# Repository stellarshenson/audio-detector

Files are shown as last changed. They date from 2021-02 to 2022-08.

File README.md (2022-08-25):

# Audio Trigger / Detector
This device listens for an audio signal at the RCA input and in response turns the audio equipment on using IR remote code or a relay. It als turns the audio equipment off when there was no audio signal detected for longer than 10min

## Initial Setup ##

### Installation ###
* Connect the RCA splitter to the RCA socket of the device. 
* Connect one end of the 3.5mm jack cable to the device and the other one to the audio amplifier IR input.
* Connect mini-usb power cable 

### Use ###
When powered, system indicates if any pre-recorded IR codes were found by blinking slowly every 2 seconds. 
If not, the fast blinkng indicates that you need to set-up the device. You need to press and hold the button. 

It will initiate 2-stage recording, first AUDIO START code and AUDIO STOP code. 
System indicates the recording status with a LED: slow blinking for the 1-st stage and fast blinking for the 2-nd. 

Setting up device sensitivity is simple - done by pressing the device button once while playing audio.
The device will listen to the audio signal for a short while and set the sensitivity to the given audio volume.

### Status Leds ###
* **fast blinking after startup** - device was not configured yet, hold button to record IR codes and press button once to record trigger audio volume
* **slow blinking after startup** - everything is ok, device waits for the audio signal
* **led stays on** - audio detected

* **fast blinking after button hold** - device waits for your first infrared remote signal
* **slower blinking after button hold** - device waits for your second infrared remote signal
* **fast blinking after button press** - device learns the volume level for which it should trigger

## Arduino ##
The board used is the Arduino Nano and the libraries:
* **arduino-fsm stellarshenson fork** - State Machine was implemented with arduino_fsm state machine library https://github.com/jonblack/arduino-fsm. This project however uses my fork of the library to allow timed transitions reset: https://github.com/stellarshenson/arduino-fsm. Pull was already requested from the *arduino-fsm* owner, hopefully my fork will be merged soon
* **IRRemote v2.6.1** - IR code recording and sending was implemented with library https://github.com/z3t0/Arduino-IRremote
* **JLed v4.11** - non-blocking led library used for various blinking patterns
* **EnableInterrupt v1.1.0** - simple interrupt driver
* **Smoothed 1.2.0** - moving average for signal detection (detecting averaged value)

## State Machine ##
Diagram was generated by http://asciiflow.com/. System defines 4 states:
* state_audio_sense - the default state, device listens for an audio signal
* state_ircode_record - active after holding the button, records remote control codes
* state_audio_start - active when audio was detected, starts the audio system and moves to state_audio_enabled
* state_audio_enabled - active when audio is enabled

					+---------------------+
					| state_ircode_record |
					+---------+--------+--+
							  ^        |
		TRIGGER_IRCODE_RECORD |        | TRIGGER_IRCODE_RECORDED
							  |        v
					+---------+--------+--+
					| state_audio_sense   +----------------------+
					+-------------+-------+                      |
								  ^                              |
		   TRIGGER_AUDIO_DISABLED |         TRIGGER_AUDIO_SENSED |
								  |                              v
					+-------------+-------+             +--------+-----------+
					| state_audio_enabled +<-----+------+ state_audio_start  |
					+---------------------+      |      +--------------------+
												 +
											TRIGGER_AUDIO_ENABLED

## Circuit and PCB ##
Below are the electronics circuit diagram and the board files (600dpi PNG images) for the PCB fabrication

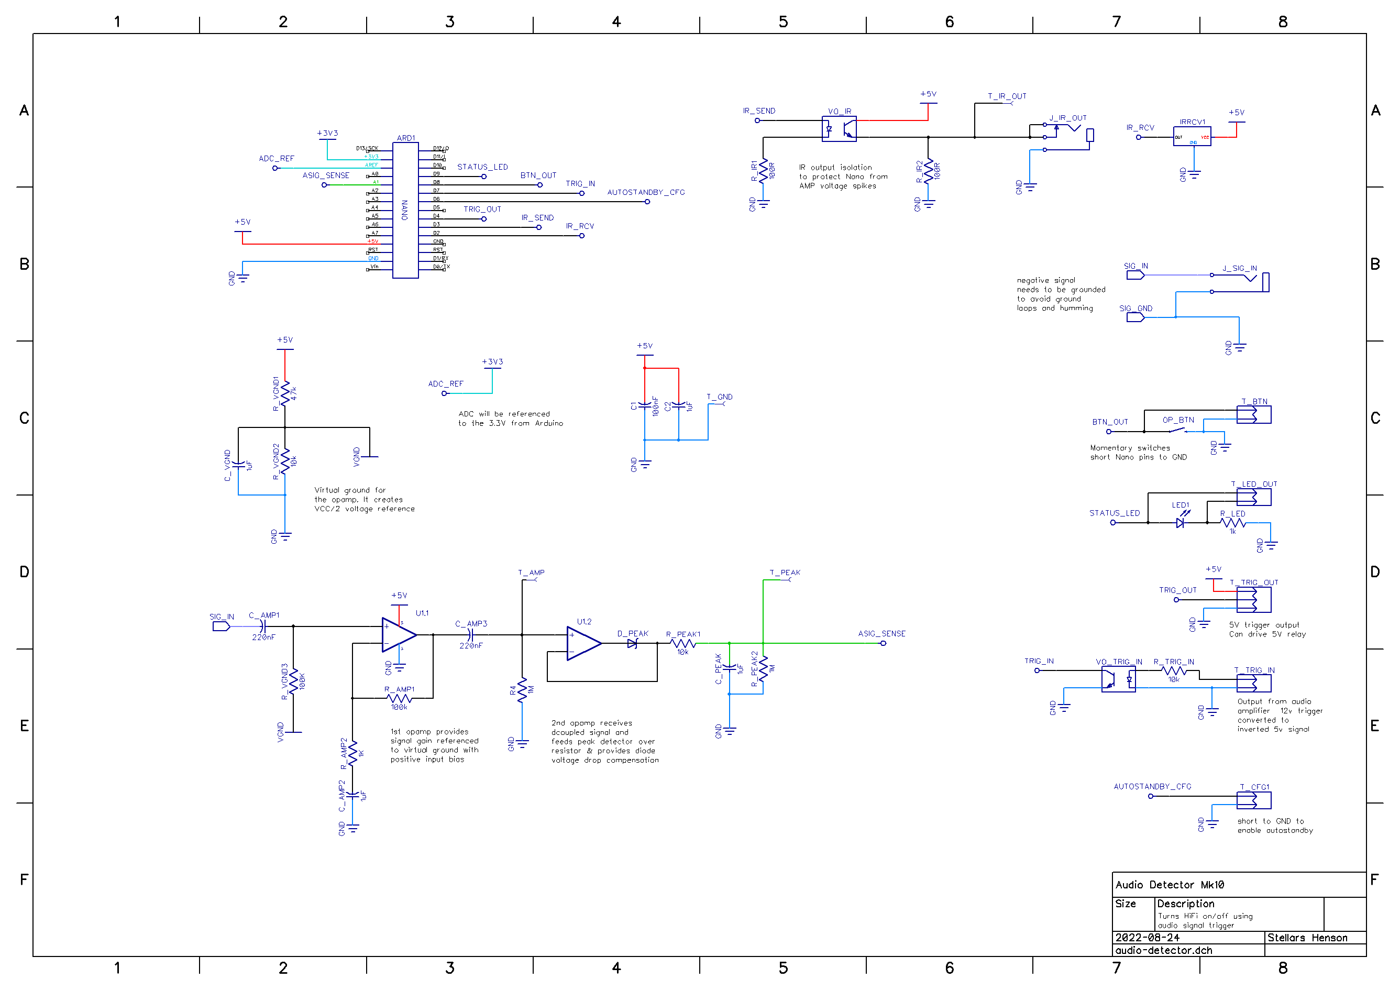
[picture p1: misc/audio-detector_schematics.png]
schematics

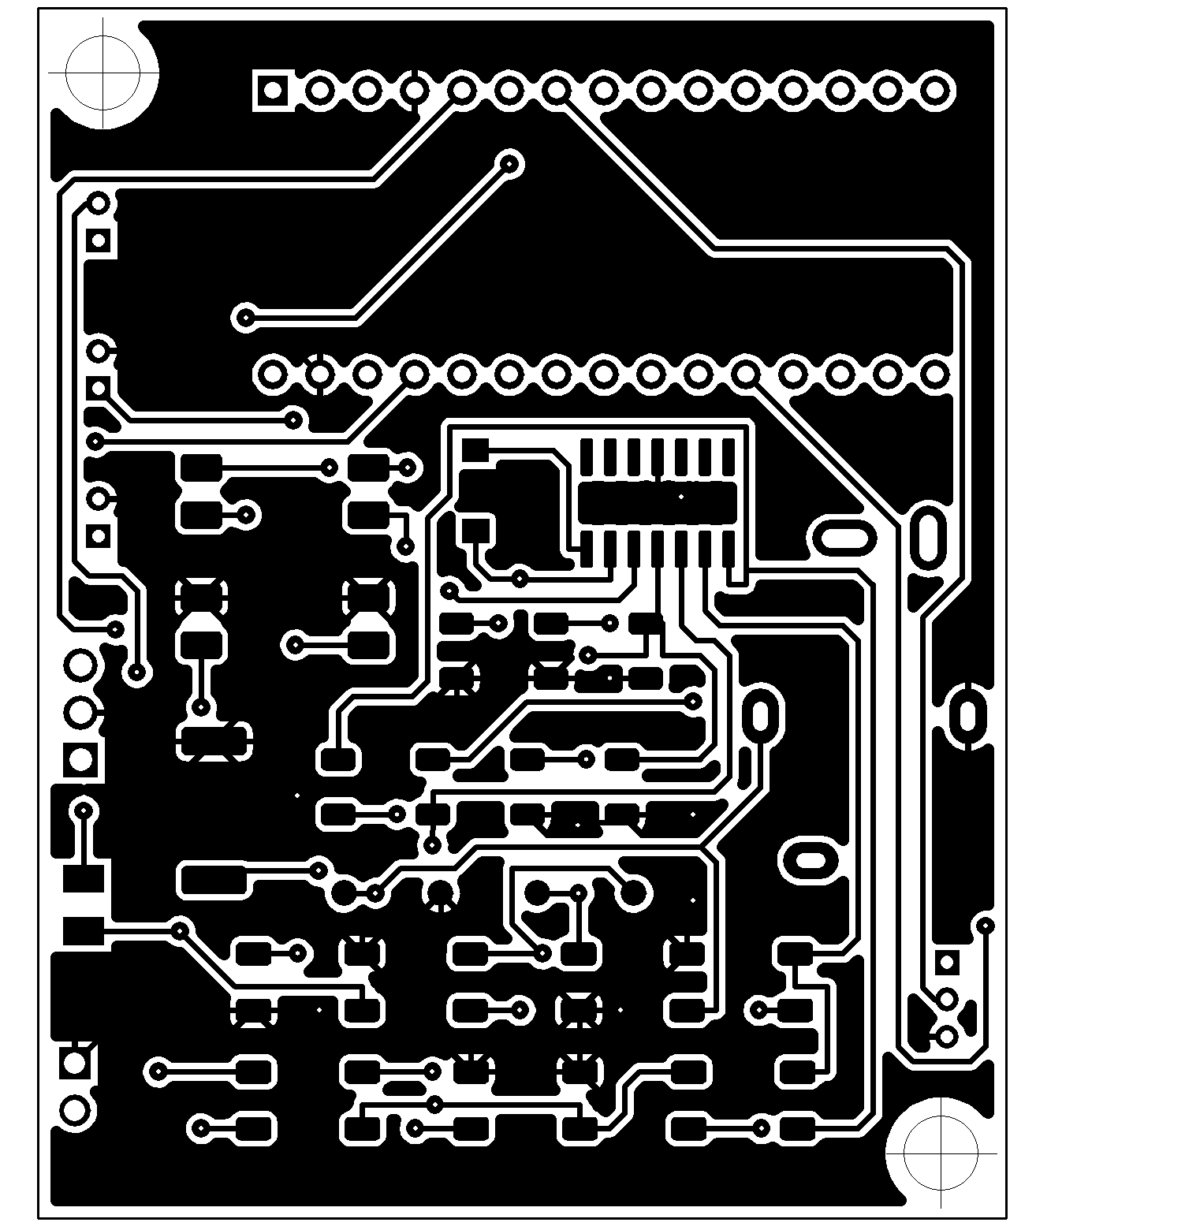
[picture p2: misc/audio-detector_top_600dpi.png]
top

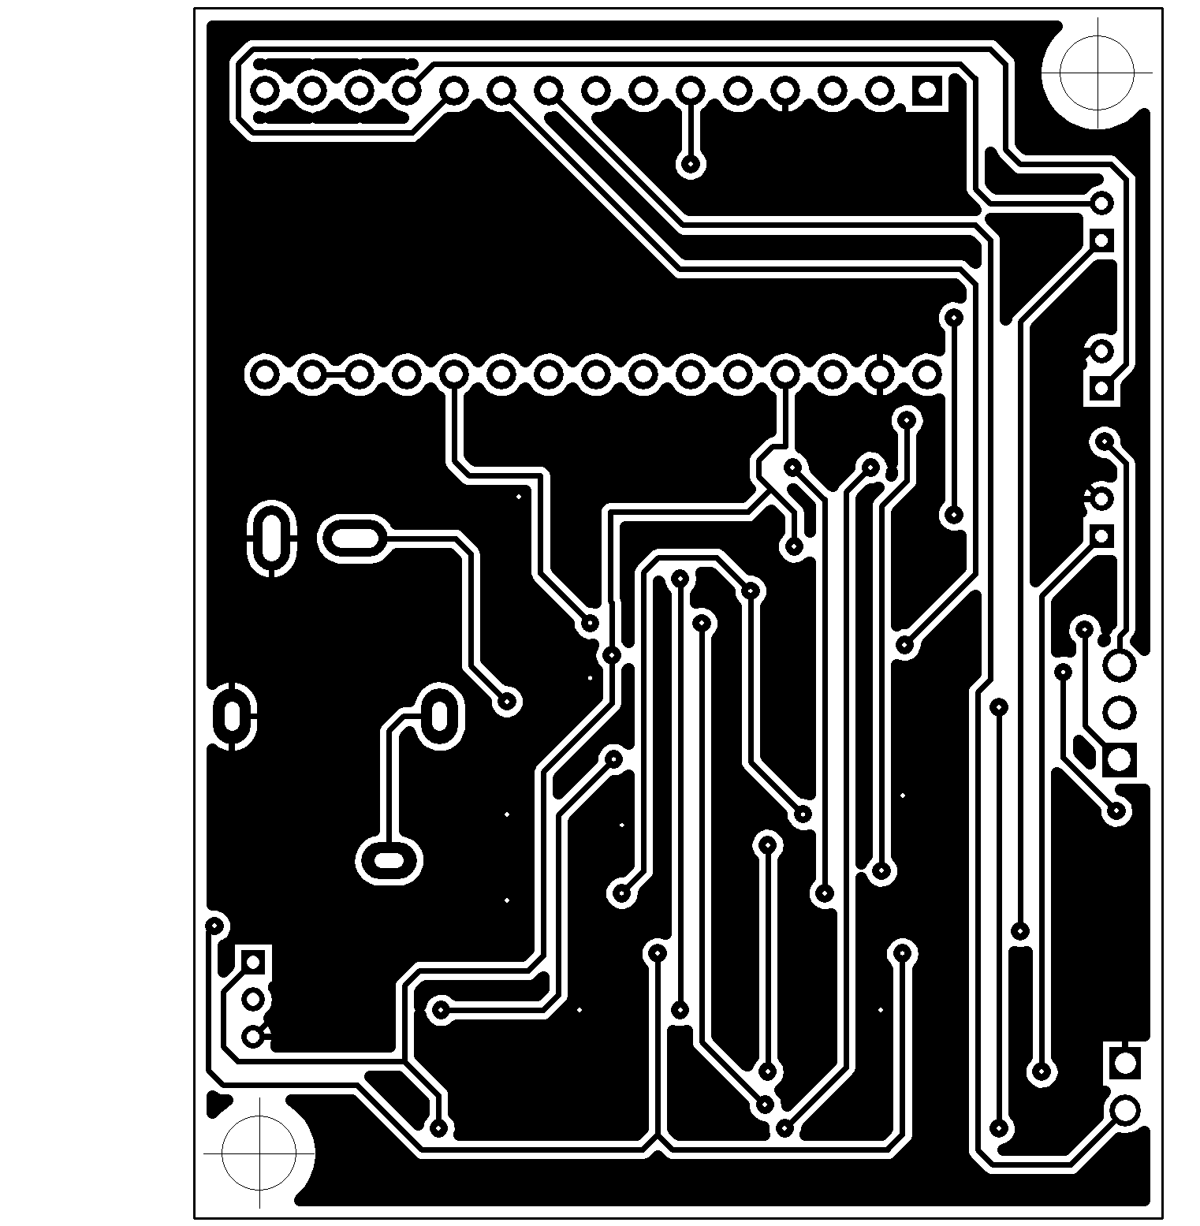
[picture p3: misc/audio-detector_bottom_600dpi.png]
bottom

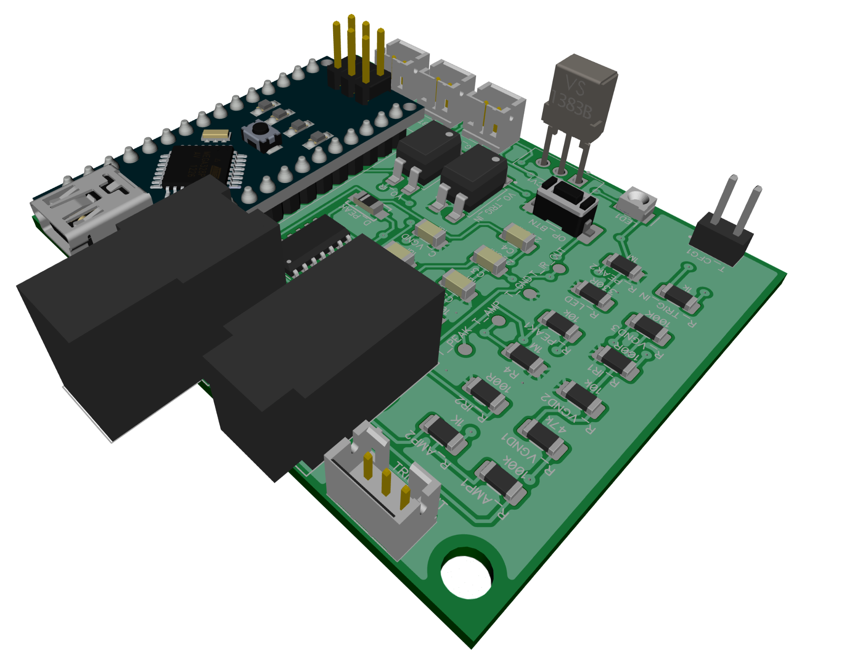
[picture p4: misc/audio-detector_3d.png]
3d

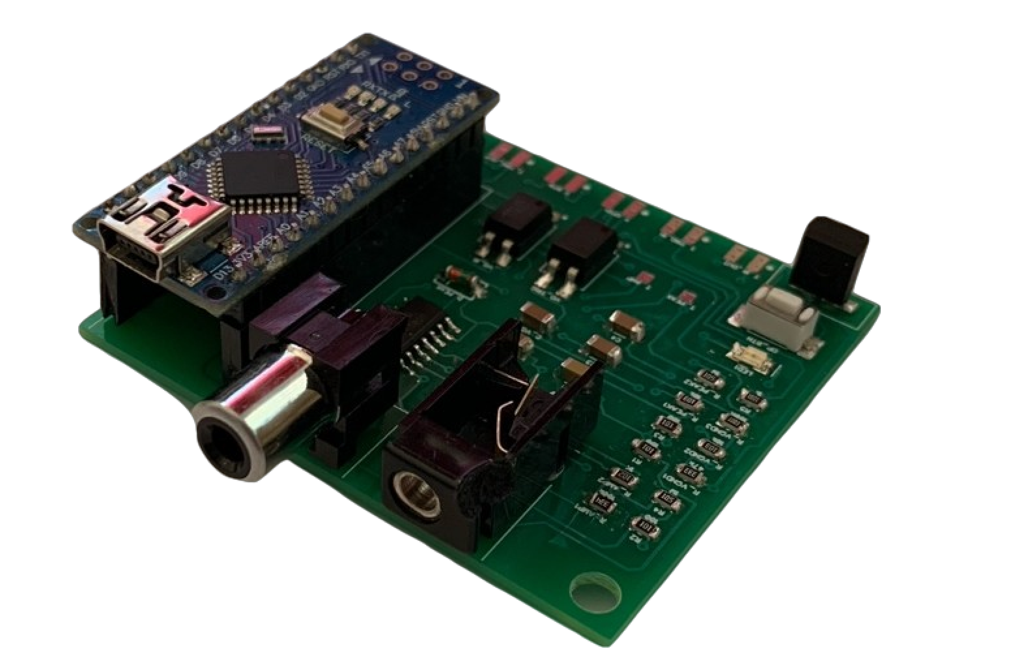
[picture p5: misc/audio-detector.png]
assembled


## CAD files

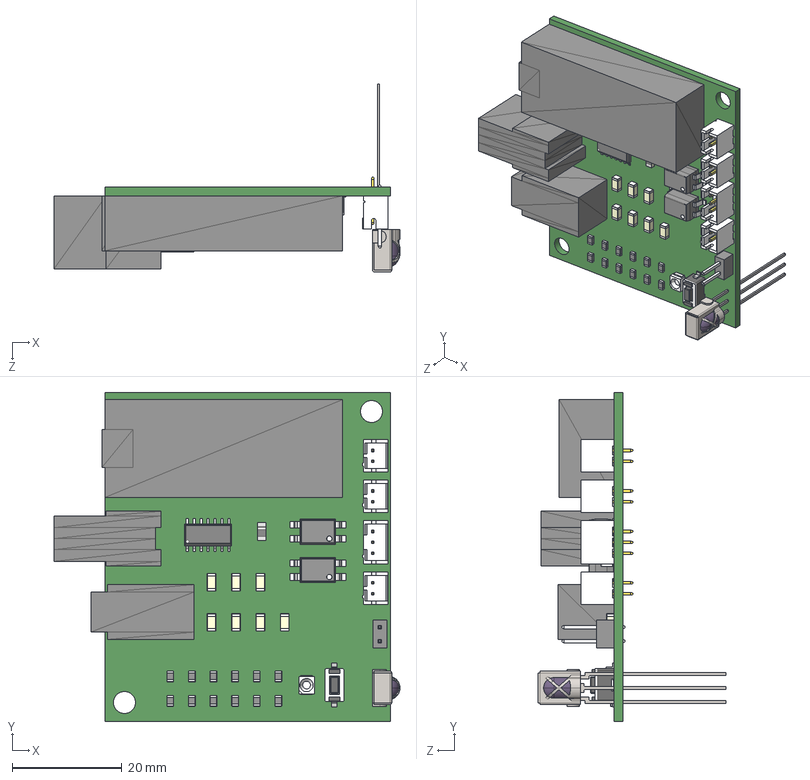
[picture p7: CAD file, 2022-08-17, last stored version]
misc/audio_detector_mk9.step
63.0 x 60.0 x 34.2 mm
Board_audio_detector_mk9
CAP_1206_N x 7
dio_1206
VS1383B
aa3528
Tactile_Switch_SMD
RES_0805_N x 12
B2B-PH-K-S x 3
B3B-PH-K-S
soic-14_150mil
TV-817S-A x 2
ARDUINO_NANO
Unitra_3.5mm_Audio_Jack
RCJ-041

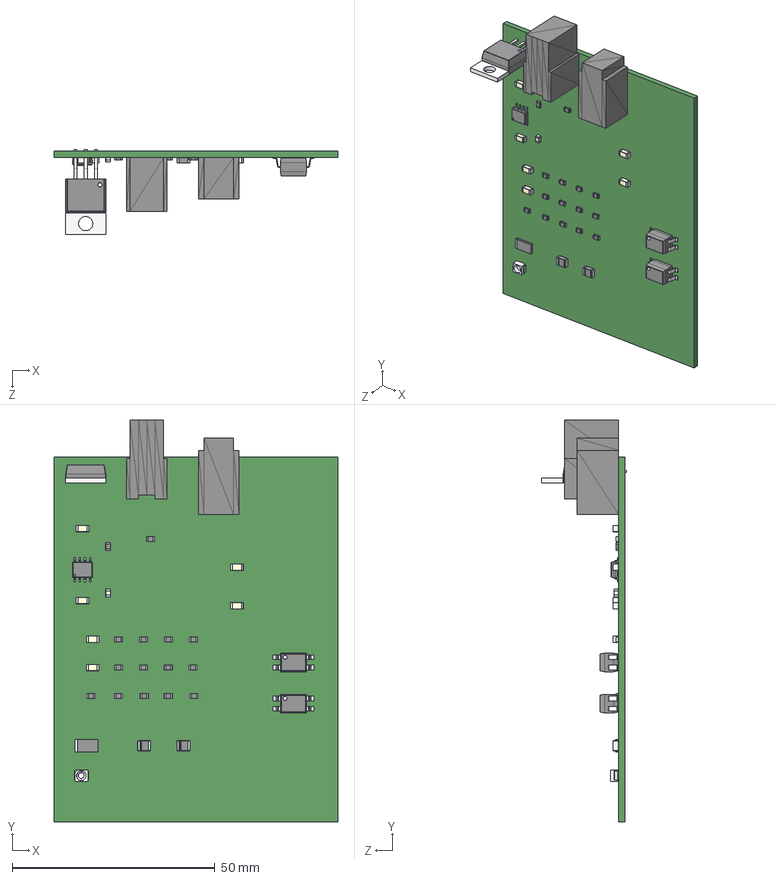
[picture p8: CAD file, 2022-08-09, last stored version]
misc/audio-detector.step
70.0 x 99.2 x 20.9 mm
Board_audio-detector
CAP_1206_N x 6
CAP_0805_N
DIO_1210_N x 2
ICL7660CSA
TSOP2236
aa3528
SWITCH_SMD_3x6mm
RES_0805_N x 15
TV-817S-A x 2
Unitra_3.5mm_Audio_Jack
RCJ-041

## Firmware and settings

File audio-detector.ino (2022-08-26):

/*
  Audio detector that triggers on the audio signal at the RCA socket and turns on (and off)
  your audio system using Infrared Remote signal and/or a Relay

                     +-----+
        +------------| USB |------------+
        |            +-----+            |
   B5   | [ ]D13/SCK        MISO/D12[ ] |   B4
        | [ ]3.3V           MOSI/D11[ ]~|   B3
        | [ ]V.ref     ___    SS/D10[ ]~|   B2
   C0   | [ ]A0       / N \       D9[ ]~|   B1
   C1   | [ ]A1      /  A  \      D8[ ] |   B0
   C2   | [ ]A2      \  N  /      D7[ ] |   D7
   C3   | [ ]A3       \_0_/       D6[ ]~|   D6
   C4   | [ ]A4/SDA               D5[ ]~|   D5
   C5   | [ ]A5/SCL               D4[ ] |   D4
        | [ ]A6              INT1/D3[ ]~|   D3
        | [ ]A7              INT0/D2[ ] |   D2
        | [ ]5V                  GND[ ] |
   C6   | [ ]RST                 RST[ ] |   C6
        | [ ]GND   5V MOSI GND   TX1[ ] |   D0
        | [ ]Vin   [ ] [ ] [ ]   RX1[ ] |   D1
        |          [ ] [ ] [ ]          |
        |          MISO SCK RST         |
        | NANO-V3                       |
        +-------------------------------+

  26 Mar 2020: code has been tested and all works with NAD326bee amplifier and Yamaha WXAD-10 streamer
  20 Aug 2022: updated the code with the moving average to elliminate voltage spikes

  Copyright by Stellars Henson 2020-2022
*/

#include <EEPROM.h>
#include <IRremote.h>         //version 2.6.1
#include <Fsm.h>              //arduino-fsm fork by Stellars Henson https://github.com/stellarshenson/arduino-fsm
#include <EnableInterrupt.h>  //version 1.1.0
#include <jled.h>             //version 4.11
#include <Smoothed.h>         //version 1.2.0

#define OUTPUT_IRCODE_SEND_PIN 3 //pin to send the IR code with via optocoupler
#define INPUT_IRCODE_RECV_PIN 2 //pin connected to IR phototransistor
#define INPUT_BUTTON_PIN 8 //learn signal level with single press, learn IR codes on holdpress
#define OUTPUT_STATUS_LED_PIN 9 //single LED
#define OUTPUT_AUDIO_ENABLED_PIN 4 //set to high when audio is enabled
#define INPUT_AUDIOTRIGGER_PIN 7 //connected to the optocoupler that detects the 12V trigger from the amp
#define INPUT_AUDIOSENSE_ADC_PIN A1  //sense audio with ADC. Vref should be 3v3
#define INPUT_CONFIG_AUTOSTANDBY_PIN 6 //configuration pin pullup. If GND than autostandby will be used. 

#define DEBUG_LEVEL 2 //0 - debug off, 1 - essential messages, 2 - full diagnostics
#define AUDIO_START_TIMEOUT 3000 //timeout for the audio start detection
#define AUDIO_STANDBY_TIMEOUT 10* 60000 //timeout for the audio shutdown if no signal (10min)
#define AUDIO_ENABLED_SENSE_INTERVAL 1* 60000 //timeout for checking audio signal in AUDIO_ENABLED (1min)
#define AUDIOSENSE_INIT_THRESHOLD 300 //initial threshold if no config available
#define AUDIOSENSE_AVG_SAMPLES 50 //number of samples for averaging
#define AUDIOSENSE_ADC_INTERVAL 50 //time between samples
#define STARTUP_STABILISE_DURATION 3000 //let the system tabilise for a while (3s)

//triggers for the FSM
#define TRIGGER_IRCODE_RECORD 1
#define TRIGGER_IRCODE_RECORDED 2
#define TRIGGER_AUDIO_DETECTED 3
#define TRIGGER_AUDIO_ENABLED 4
#define TRIGGER_AUDIO_DISABLED 5
#define TRIGGER_AUDIO_LEARN 6
#define TRIGGER_AUDIO_LEARNED 7

//IR receiver setup
#define EXCLUDE_EXOTIC_PROTOCOLS // saves around 900 bytes program space with IRRemote v3.2+
IRrecv irrecv(INPUT_IRCODE_RECV_PIN);
IRsend irsend;
decode_results results;

//nonblocking LED setup
auto led_sense_noconfig = JLed(OUTPUT_STATUS_LED_PIN).Blink(250, 1000).Forever(); //quick blinking if no config
auto led_sense_configok = JLed(OUTPUT_STATUS_LED_PIN).Blink(1000, 2000).Forever(); //long blinking if everything is ok
auto led_audio_enabled =  JLed(OUTPUT_STATUS_LED_PIN).On();
auto led_audio_disabled = JLed(OUTPUT_STATUS_LED_PIN).Off();
auto led_audio_learning = JLed(OUTPUT_STATUS_LED_PIN).Blink(750, 250).Forever();
auto led_ir_recording_1 = JLed(OUTPUT_STATUS_LED_PIN).Blink(100, 100).Forever();
auto led_ir_recording_2 = JLed(OUTPUT_STATUS_LED_PIN).Blink(500, 500).Forever();
JLed led_active = led_sense_noconfig; //this will be set to the active led scheme

// Storage for the recorded code
void sendCode(uint8_t repeat, uint8_t codeType, uint8_t codeLen, unsigned long codeValue);
void storeCode(decode_results *results, int8_t &codeType, uint8_t &codeLen, unsigned long &codeValue);


uint8_t startAudioCodeType = 255; // The type of code
uint8_t startAudioCodeLen; // The length of the code
unsigned long startAudioCodeValue; // The code value if not raw

uint8_t stopAudioCodeType = 255; // The type of code
uint8_t stopAudioCodeLen; // The length of the code
uint32_t stopAudioCodeValue; // The code value if not raw

uint8_t toggle = 0; // The RC5/6 toggle state
uint16_t rawCodes[RAW_BUFFER_LENGTH]; // The durations if raw
uint8_t irCodesAvailable = 0; //if ircodes were recorded

uint8_t audioTriggerAvailable = 0; //if 12V trigger is available. Audio enable timeout sets this to 0, detection of the 12V trigger sets this to 1. We can also detect this with an audio jack (it has detect input feature)
uint8_t autoStandbyEnabled = 0; //enabled by the configuration pin INPUT_CONFIG_AUTOSTANDBY_PIN

//interrupt driver
#define BUTTON_HOLDPRESS 2
#define BUTTON_SINGLEPRESS 1
#define HOLDPRESS_TIMEOUT 600
volatile uint8_t button_detected = 0;
void on_button_irq(); //irq driver
void on_button_update(); //updated in the loop button sensing for single and long press

uint32_t audiosense_millis = 0; //used to measure time before consecutive audio signal checks in AUDIO_ENABLED state

//ADC smoothing setup
Smoothed <float> audioSenseMovingAvg;
Smoothed <float> audioSenseMovingAvg_learn;
uint16_t audioSenseLearnCounter = 0;
uint16_t audioSenseThreshold = AUDIOSENSE_INIT_THRESHOLD;


//FSM - set up of the state machine
void on_ircode_record_enter();
void on_ircode_record_loop();
void on_ircode_record_exit();
void on_audio_learn_enter();
void on_audio_learn_loop();
void on_audio_learn_exit();
void on_audio_sense_enter();
void on_audio_sense_loop();
void on_audio_sense_exit();
void on_audio_start_enter();
void on_audio_start_loop();
void on_audio_start_exit();
void on_audio_enabled_enter();
void on_audio_enabled_loop();
void on_audio_enabled_exit();
void on_audio_start_timed_trans_audio_enabled();
State state_audio_sense(on_audio_sense_enter, on_audio_sense_loop, on_audio_sense_exit); //idle state, waiting for audio signal
State state_ircode_record(on_ircode_record_enter, on_ircode_record_loop, on_ircode_record_exit); //state where IR codes are recorded for start and stop audio
State state_audio_learn(on_audio_learn_enter, on_audio_learn_loop, on_audio_learn_exit); //state where threshold for audio detection is set
State state_audio_start(on_audio_start_enter, on_audio_start_loop, on_audio_start_exit); //state where audio was detected and amplifier is switched on. this state waits for 12v standby-on or timeout (if not 12v trigger available)
State state_audio_enabled(on_audio_enabled_enter, on_audio_enabled_loop, on_audio_enabled_exit); //idle state where audio is enabled. keeps checking if the audio is still on
Fsm   fsm(&state_audio_sense); //set up the bootstrap state to start with

//debug and commandline
uint8_t debug_plot_enabled = 0; //plot disabled by default
void cmd_poll(HardwareSerial &serial, void *handler(int, String*));
void cmd_handler(int argc, String* argv);

//reboot function
void(* reboot) (void) = 0;

void setup() {
  //start serial and command listener
  Serial.begin(9600);

  //setup pins
  pinMode(INPUT_BUTTON_PIN, INPUT_PULLUP);
  pinMode(INPUT_AUDIOTRIGGER_PIN, INPUT_PULLUP);
  pinMode(OUTPUT_STATUS_LED_PIN, OUTPUT);
  pinMode(OUTPUT_AUDIO_ENABLED_PIN, OUTPUT);
  pinMode(INPUT_AUDIOSENSE_ADC_PIN, INPUT);
  pinMode(INPUT_CONFIG_AUTOSTANDBY_PIN, INPUT_PULLUP);
  digitalWrite(OUTPUT_AUDIO_ENABLED_PIN, LOW);

  //read ircode from EEPROM
  startAudioCodeValue = ( (unsigned long)EEPROM.read(0)) | ( (unsigned long)EEPROM.read(1) << 8) | ((unsigned long) EEPROM.read(2) << 16) | ( (unsigned long)EEPROM.read(3) << 24);
  startAudioCodeLen = EEPROM.read(4);
  startAudioCodeType = EEPROM.read(5);

  stopAudioCodeValue = ( (unsigned long)EEPROM.read(6)) | ( (unsigned long)EEPROM.read(7) << 8) | ((unsigned long) EEPROM.read(8) << 16) | ( (unsigned long)EEPROM.read(9) << 24);
  stopAudioCodeLen = EEPROM.read(10);
  stopAudioCodeType = EEPROM.read(11);

  //recover audio sense threshold for ADC
  audioSenseThreshold = ( (uint16_t)EEPROM.read(12)) | ( (uint16_t)EEPROM.read(13) << 8);

  //initiate status led to indicate if config ok or not available
  if (startAudioCodeType != 255 && stopAudioCodeType != 255) irCodesAvailable = 1;
  else irCodesAvailable = 0;

  //read autostandby status. pin has a pullup.
  autoStandbyEnabled = digitalRead(INPUT_CONFIG_AUTOSTANDBY_PIN) == LOW;

  if (DEBUG_LEVEL) Serial.print(F("[INIT] Restoring IR codes, AUDIO START: "));
  if (DEBUG_LEVEL) Serial.print(startAudioCodeValue, HEX);
  if (DEBUG_LEVEL) Serial.print(F(" , AUDIO STOP: "));
  if (DEBUG_LEVEL) Serial.print(stopAudioCodeValue, HEX);
  if (DEBUG_LEVEL) Serial.print(F(" , SENSE THRESHOLD: "));
  if (DEBUG_LEVEL) Serial.println(audioSenseThreshold, DEC);
  if (DEBUG_LEVEL && irCodesAvailable != 1) Serial.println(F("[INIT] IR codes not available"));
  if (DEBUG_LEVEL) Serial.print(F("[INIT] Automatic standby is: "));
  if (DEBUG_LEVEL) Serial.println( digitalRead(autoStandbyEnabled) ? "OFF" : "ON" );

  //initialise state machine
  fsm.add_transition(&state_audio_sense, &state_ircode_record, TRIGGER_IRCODE_RECORD, NULL);
  fsm.add_transition(&state_ircode_record, &state_audio_sense, TRIGGER_IRCODE_RECORDED, NULL);
  fsm.add_transition(&state_audio_sense, &state_audio_learn, TRIGGER_AUDIO_LEARN, NULL);
  fsm.add_transition(&state_audio_learn, &state_audio_sense, TRIGGER_AUDIO_LEARNED, NULL);
  fsm.add_transition(&state_audio_sense, &state_audio_start, TRIGGER_AUDIO_DETECTED, NULL);
  fsm.add_transition(&state_audio_start, &state_audio_enabled, TRIGGER_AUDIO_ENABLED, NULL);
  fsm.add_transition(&state_audio_enabled, &state_audio_sense, TRIGGER_AUDIO_DISABLED, NULL);
  fsm.add_transition(&state_audio_enabled, &state_audio_learn, TRIGGER_AUDIO_LEARN, NULL);
  fsm.add_transition(&state_audio_enabled, &state_ircode_record, TRIGGER_IRCODE_RECORD, NULL);
  fsm.add_timed_transition(&state_audio_start, &state_audio_enabled, AUDIO_START_TIMEOUT, on_audio_start_timed_trans_audio_enabled);
  fsm.add_timed_transition(&state_audio_enabled, &state_audio_sense, AUDIO_STANDBY_TIMEOUT, on_audio_enabled_timed_trans_audio_sense);

  //enable audiosense averaging
  audioSenseMovingAvg.begin(SMOOTHED_AVERAGE, AUDIOSENSE_AVG_SAMPLES);
  audioSenseMovingAvg_learn.begin(SMOOTHED_AVERAGE, AUDIOSENSE_AVG_SAMPLES);

  //print command prompt
  Serial.println(F("[INIT] type 'help' for commands list"));
}

void loop() {
  fsm.run_machine(); //run state loops
  led_active.Update(); //run led driver
  on_button_update(); //run button sensing
  cmd_poll(Serial, cmd_handler); //run command interpreter
}

// *******************************
// STATE MACHINE
// *******************************


// STATE_AUDIOSENSE

/**
  only announces the transition
*/
void on_audio_sense_enter() {
  if (DEBUG_LEVEL) Serial.println(F("[AUDIO SENSE] Start. Listening for audio and ircode record button"));

  //interrupt initialisation. check initial audio signal status
  button_detected = 0;
  enableInterrupt(INPUT_BUTTON_PIN, on_button_irq, CHANGE);

  //light LED for status and configuration
  if (irCodesAvailable == 1) led_active = led_sense_configok;
  else led_active = led_sense_noconfig;
}

/**
  waits for either ircode record button trigger or for audio signal
  ircode button -> goes to ircode recording
  audiosense signal -> goes to start audio
  audio and ircode button detection is driven by interrupts
*/
void on_audio_sense_loop() {
  boolean _audio_sensed = senseAudio() > audioSenseThreshold;
  if ( millis() < STARTUP_STABILISE_DURATION ) _audio_sensed = false; //ignore signal if still stabilising the system

  // hold button to enable recording ircode
  if (button_detected == BUTTON_HOLDPRESS) {
    if (DEBUG_LEVEL) Serial.println(F("[AUDIO SENSE] IRCode recording detected"));
    fsm.trigger(TRIGGER_IRCODE_RECORD);
  }

  // button to enable learning audio threshold
  if (button_detected == BUTTON_SINGLEPRESS) {
    if (DEBUG_LEVEL) Serial.println(F("[AUDIO SENSE] Audiosense learning detected"));
    fsm.trigger(TRIGGER_AUDIO_LEARN);
  }

  // this is detected with ADC pin INPUT_AUDIOSENSE_ADC_PIN
  if (_audio_sensed) {
    if (DEBUG_LEVEL) Serial.println(F("[AUDIO SENSE] Audio signal detected"));
    fsm.trigger(TRIGGER_AUDIO_DETECTED);
  }
}

/**
  signals exit from the state
*/
void on_audio_sense_exit() {
  if (DEBUG_LEVEL == 2) Serial.println(F("[AUDIO SENSE] Exit. Disabling audio signal detection"));
  disableInterrupt(INPUT_BUTTON_PIN);

  //clear audiosense averaging
  audioSenseMovingAvg.clear();
}


// IRCODE RECORD STATE

/**
  enables IR receiver and turns recording LED on
  it also resets codes recorded previously
*/
void on_ircode_record_enter() {
  // enable receiver
  irrecv.enableIRIn();

  //enable recording led
  if (DEBUG_LEVEL) Serial.println(F("[IRCODE RECORD] Start.  Enabling IR receiver"));
  led_active = led_ir_recording_1;

  //reset all previosu codes
  startAudioCodeValue = 0;
  startAudioCodeType = 255;
  stopAudioCodeValue = 0;
  stopAudioCodeType = 255;
}

/**
  waits until IR remote sends the IR code
  - records audio start code and saves to EEPROM and waits for recoding of the audio stop
  - records audio stop code and saves to EEPROM
  after this goes back to audio sense state

  the STORED_LED will be flashing with 1HZ when only one code was recorded and will
  be turned on permanently when all codes were recorded
*/
void on_ircode_record_loop() {
  //read and decode the ircode, ircode was received with the interrupts
  if (irrecv.decode(&results)) {
    //record start audio code
    if ( startAudioCodeType == 255 ) {
      if (DEBUG_LEVEL) Serial.println(F("[IRCODE RECORD][1/2] - AUDIO START ircode detected"));
      storeCode(&results, startAudioCodeType, startAudioCodeLen, startAudioCodeValue);

      //write the to eeprom and report on serial
      EEPROM.update(0, startAudioCodeValue);
      EEPROM.update(1, startAudioCodeValue >> 8);
      EEPROM.update(2, startAudioCodeValue >> 16);
      EEPROM.update(3, startAudioCodeValue >> 24);
      EEPROM.update(4, startAudioCodeLen);
      EEPROM.update(5, startAudioCodeType);
      if (DEBUG_LEVEL == 2) Serial.print(F("[IRCODE RECORD][1/2] Saved value: "));
      if (DEBUG_LEVEL) Serial.println(startAudioCodeValue, HEX);
      if (DEBUG_LEVEL == 2) Serial.println(F("[IRCODE RECORD][1/2] Waiting for AUDIO STOP ircode"));

      delay(500);
      irrecv.resume(); //resume recording for the stop code

      //enable recording part #2 led
      led_active = led_ir_recording_2;
    }
    //record stop audio code
    else if ( startAudioCodeType != 255 && stopAudioCodeType == 255 ) {
      if (DEBUG_LEVEL) Serial.println(F("[IRCODE RECORD][2/2] AUDIO STOP ircode detected"));
      storeCode(&results, stopAudioCodeType, stopAudioCodeLen, stopAudioCodeValue);

      //write the to eeprom and report on serial
      EEPROM.update(6, stopAudioCodeValue);
      EEPROM.update(7, stopAudioCodeValue >> 8);
      EEPROM.update(8, stopAudioCodeValue >> 16);
      EEPROM.update(9, stopAudioCodeValue >> 24);
      EEPROM.update(10, stopAudioCodeLen);
      EEPROM.update(11, stopAudioCodeType);
      if (DEBUG_LEVEL == 2) Serial.print(F("[IRCODE RECORD][2/2] Saved value: "));
      if (DEBUG_LEVEL) Serial.println(stopAudioCodeValue, HEX);

      //trigger transition
      fsm.trigger(TRIGGER_IRCODE_RECORDED);  //trigger transition only after audio stop code was recorded
    }
  }
}

/**
  announces exit from ircode recording state and turns off recording LED
*/
void on_ircode_record_exit() {
  if (DEBUG_LEVEL == 2) Serial.println(F("[IRCODE RECORD] Exit. Disabling receiver"));

  //mark that ir codes are available now
  irCodesAvailable = 1;
}

// AUDIO LEARN STATE

/**
  reset learning and indicate with LED that learningg started
*/
void on_audio_learn_enter() {
  if (DEBUG_LEVEL == 2) Serial.println(F("[AUDIOSENSE LEARN] Entering state. Resetting threshold and counter"));
  led_active = led_audio_learning;
  audioSenseLearnCounter = 0;
  audioSenseThreshold = 0;
}

/**
  start smooting the audio over the next SAMPLES and record result to EEPROM
*/
void on_audio_learn_loop() {
  static uint32_t _lastSenseMillis = millis();

  if (millis() > _lastSenseMillis + AUDIOSENSE_ADC_INTERVAL) {
    if (audioSenseLearnCounter++ < AUDIOSENSE_AVG_SAMPLES) {
      float _value = analogRead(INPUT_AUDIOSENSE_ADC_PIN);

      //reset last sense millis
      _lastSenseMillis = millis();
      audioSenseMovingAvg_learn.add(_value);

      //plot only if enabled
      if (debug_plot_enabled) {
        Serial.print(F("[Learn]  minimum: 0, maximum: 1024, sensed_value: "));
        Serial.print(_value);
        Serial.print(F(", average_value:  "));
        Serial.println(audioSenseMovingAvg_learn.get());
      }
    } else {
      //set threshold to the measured average but it must be at least 10
      audioSenseThreshold = audioSenseMovingAvg_learn.get() > 10 ? audioSenseMovingAvg_learn.get() : 10;

      //save to EEPROM
      EEPROM.update(12, audioSenseThreshold);
      EEPROM.update(13, audioSenseThreshold >> 8);

      //trigger transition
      fsm.trigger(TRIGGER_AUDIO_LEARNED);
    }
  }
}

/**
  announce recorded value and exit
*/
void on_audio_learn_exit() {
  if (DEBUG_LEVEL == 2) {
    Serial.print(F("[AUDIOSENSE LEARN] Exit. New threshold set to: "));
    Serial.println(audioSenseThreshold, DEC);
  }

  //disable audiosense averaging
  audioSenseMovingAvg_learn.clear();
}

// AUDIO START STATE

/**
  sends recorded IR code on enter
*/
void on_audio_start_enter() {
  Serial.println(F("[AUDIO START] Start. Sending AUDIO START IR code and monitoring"));

  //initialise trigger sense
  audioTriggerAvailable = 0;

  //send audio start IR signal
  sendCode(0, startAudioCodeType, startAudioCodeLen, startAudioCodeValue); //send recorded or saved IR code without repeat
}

/**
  waits for the external 12V trigger (typically output from an amplifier
  MK2 - if the external 12V trigger was not detected in AUDIOTRIGGER_TIMEOUT, system enables its own 12V trigger relay
  once 12V trigger was enabled or detected, move to AUDIO_ENABLED state
*/
void on_audio_start_loop() {
  uint8_t audioTriggerState = digitalRead(INPUT_AUDIOTRIGGER_PIN);  //read the status of the external 12V trigger via optocoupler circuit connected to GND

  //detecting status of the 12v trigger line
  //it stays this way, we are not trying to detect the signal, just the state
  if (audioTriggerState == LOW) {
    if (DEBUG_LEVEL) Serial.println(F("[AUDIO START] Audio trigger detected"));
    audioTriggerAvailable = 1; //12V audio trigger is available, no need for timeout
    fsm.trigger(TRIGGER_AUDIO_ENABLED); //initiate state transition
  }
}

/**
  announce exit from the audio start state
*/
void on_audio_start_exit() {
  if (DEBUG_LEVEL == 2) Serial.println(F("[AUDIO START] Exit. Audio is on"));
}

/**
  timed transition to audio enabled state after AUDIO_START_TIMEOUT (in miliseconds)
*/
void on_audio_start_timed_trans_audio_enabled() {
  if (DEBUG_LEVEL) Serial.println(F("[AUDIO START] Timeout. Trigger not available"));
  audioTriggerAvailable = 0; //12V audio trigger is not available
}

// AUDIO ENABLED STATE

/**
  announce enter audio enabled state
*/
void on_audio_enabled_enter() {
  if (DEBUG_LEVEL) Serial.println(F("[AUDIO ENABLED] Start. Monitoring for standby"));

  //if audiotrigger is not available, enable interrupts to listen to audio signal
  if (audioTriggerAvailable == 0) {
    audiosense_millis = millis();

    if (DEBUG_LEVEL == 2) {
      Serial.print(F("[AUDIO ENABLED] Trigger not available. Enabling audio signal timeout for "));
      Serial.print(AUDIO_STANDBY_TIMEOUT / 60000, DEC);
      Serial.println(F("min"));
    }
  }

  //led for audio on
  led_active = led_audio_enabled;

  //enable output pin to indicate that audio is on
  digitalWrite(OUTPUT_AUDIO_ENABLED_PIN, HIGH);

  //interrupt initialisation for ir code recording and for threshold learning
  button_detected = 0;
  enableInterrupt(INPUT_BUTTON_PIN, on_button_irq, CHANGE);
}
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

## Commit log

2020-03-21 added initial code (arduino)
    [audio-detector.fzz]
2020-03-23 updated breadboard circuit and pin assignments
    updated the breadboard diagram to reflect changes in the code
    [audio-detector.fzz]
2020-03-23 changed code to turn off STORED led when recording
    [audio-detector.fzz]
2020-03-23 added bill of materials and changed the resistors to 470 ohm
    [audio-detector.fzz]
2020-03-23 changed status led pin to 04
2020-03-23 updated fritzing breadboard project
    [audio-detector.fzz]
2020-03-24 turned off the timeout and fixed the bb diagram
    [audio-detector.fzz]
2020-03-24 updated diagram
    [audio-detector.fzz]
2020-03-24 added optoisolators and input connectors
    [audio-detector.fzz]
2020-03-24 updated layout
    [audio-detector.fzz]
2020-03-24 layout changes
    [audio-detector.fzz]
2020-03-24 enhanced layout
    [audio-detector.fzz]
2020-03-24 optimised layout
    [audio-detector.fzz]
2020-03-25 tested the code and the diagram
    had to change some passives to make this work with the NAD360 amp
    [audio-detector.fzz]
2020-03-25 fixed diagram text
    [audio-detector.fzz]
2020-03-25 reduced code footprint
2020-03-26 fixed wiring of the IR in circuit
    [audio-detector.fzz]
2020-03-26 updated code to interrupt driven for audio detection and ircode record
2020-03-26 implemented timers for audio start and stop
2020-03-26 updated led timing
2020-03-26 updated documentation
    [audio-detector.fzz]
2020-03-26 updatted arduino-fsm disclaimer
2020-05-14 reduced memory footprint
2021-01-05 fixed audio detection when pin already energised
    [audio-detector.ino]
2021-01-10 turned to single LED design
2021-01-10 added averaging and adc sense state
2021-02-16 updated board
2021-02-20 updated schematics
2021-02-22 updated with RCA connector
2021-02-23 added schematics
2021-02-23 added frame
2021-03-14 updated circuit to SMD
    also made changes to single button operation
2021-03-14 change to one button operation
2021-04-01 fixed design with lower freq and holdpress fix
    [audio-detector.step]
2022-08-09 updated documentation, added schematics for the amplifier
    [audio-detector.step]
2022-08-12 updated description
    [audio-detector.step]
2022-08-14 updated schematics png
2022-08-14 updated with mounting holes
2022-08-15 updated with new 3d model for the button
2022-08-24 fixed issue with instability - removed PWM Led code
    [audio-detector.ino]
2022-08-24 updated with new 3.5mm socket
2022-08-25 updated to v10 with trig connector at the back
2022-08-25 updated board and readme
    [audio-detector.fzz]
2022-08-25 Update audio-detector.ino
    implemented simple commandline driver
2022-08-26 added commandline driver
2022-08-26 added stop processing to command driver
2026-10-14 build: move project to platformio layout with bundled libraries
    The sketch had no reproducible build: it depended on libraries in a
    shared folder outside the repository and on a local Arduino IDE setup.
    - move the sketch to src/ and bundle the five non-core libraries in lib/
    so the repository builds on its own
    - add platformio.ini for the Nano (old bootloader) with atmelavr pinned
    to 5.3.0, the version the firmware-avr conda environment installs
    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
2026-10-17 feat: add simavr test suite, audio level driver and eeprom backup
    The firmware had defects that could switch the amplifier at the wrong
    time: the 12V trigger path never reset the 10-minute timer, a held
    remote button saved an NEC repeat as the STOP code, an unknown protocol
    left recording stuck, and the 49.7-day millis() wrap stopped sampling.
    The threshold learned on loud music also sat above the same music.
    Add a simavr harness that runs the built ELF with board-level inputs,
    unit tests for the harness decoders, and functional tests for every
    acceptance criterion. Move audio sensing into an AudioLevel driver that
    samples in every state, clears on idle entry, learns half the playing
    level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
2026-10-17 feat: recover eeprom from a board with older firmware
    The deployed board can run firmware without the eeprom commands, so the
    backup saves the whole flash image, flashes tools/eeprom-bridge, dumps the
    EEPROM, writes the saved image back and verifies the read-back.
2026-10-20 build: adopt the copier-embedded-project v1.0.17 layout
    The project now follows the copier-embedded-project template and
    records its answers in .copier-answers.yml, so later template releases
    reach it through copier update.
    - the bundled libraries move to lib/vendor/, found through
    lib_extra_dirs, and lib/README.md lists their pinned versions
    - the EEPROM tool becomes the host package host/src/audiodetector_host/
    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
